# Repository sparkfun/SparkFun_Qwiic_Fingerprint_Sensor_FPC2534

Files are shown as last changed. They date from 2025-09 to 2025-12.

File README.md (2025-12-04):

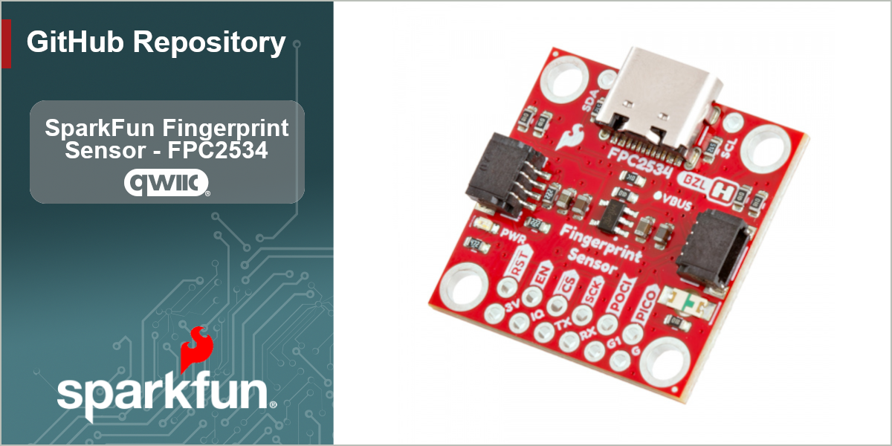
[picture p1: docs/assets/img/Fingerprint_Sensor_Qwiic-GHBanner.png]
SparkFun Fingerprint Sensor - FPC2534 (Qwiic) (https://www.sparkfun.com/sparkfun-fingerprint-sensor-fpc2534-qwiic.html)


---------------------

The SparkFun FPC2534 Qwiic Fingerprint Sensor is a powerful, dual-purpose breakout that combines professional-grade biometric security with touch navigation. Built around the advanced FPC2354 sensor from Fingerprint Cards AB (FPC), this board handles the complex processing of fingerprint enrollment, encryption, and internal storage, ensuring your data remains secure without bogging down your host microcontroller.

This sensor is a complete authentication scanner designed for our [Qwiic ecosystem](https://www.sparkfun.com/qwiic). Whether you are creating a secure access terminal, a hardware password manager, or a smart lock, the FPC2534 Fingerprint Sensor will provide you with reliable security in low-profile package.

Repository Contents
-------------------

* **/docs** - Documentation files for GitHub pages
* **/Documentation** - Data sheets, additional product information 
* **/Hardware** - Eagle design files (.brd, .sch)
* **/Production** - Production panel files (.brd)

Documentation
--------------
* **[Library](https://github.com/sparkfun/SparkFun_FPC2534_Arduino_Library)** - Arduino library for the SparkFun Fingerprint Sensor - FPC2534 (Qwiic).
* **[Hookup Guide](https://docs.sparkfun.com/SparkFun_Qwiic_Fingerprint_Sensor_FPC2534/)** - Basic hookup guide for the SparkFun Fingerprint Sensor - FPC2534 (Qwiic).

Product Versions
----------------
* [SEN-29854](https://www.sparkfun.com/sparkfun-fingerprint-sensor-fpc2534-qwiic.html) - Initial release of the SparkFun Fingerprint Sensor - FPC2534 (Qwiic)

License Information
-------------------

This product is _**open source**_! 

Please review the LICENSE.md file for license information. 

If you have any questions or concerns on licensing, please contact technical support on our [SparkFun forums](https://forum.sparkfun.com/viewforum.php?f=152).

Distributed as-is; no warranty is given.

- Your friends at SparkFun.

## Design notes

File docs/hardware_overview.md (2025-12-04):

Let's take a closer look at the FPC2534 sensor and other hardware on this Qwiic breakout.

<figure markdown>
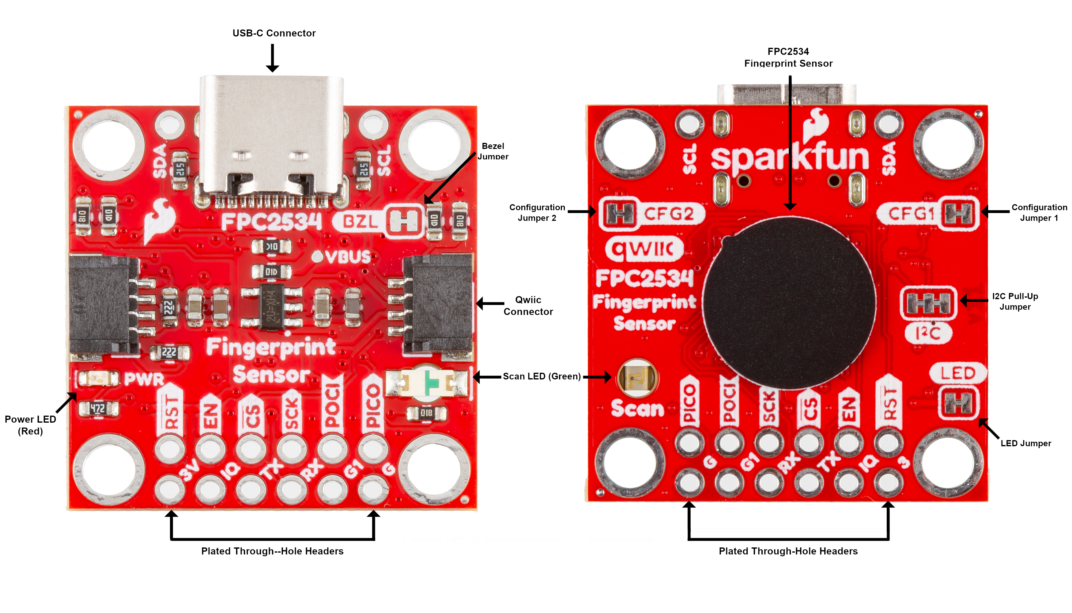
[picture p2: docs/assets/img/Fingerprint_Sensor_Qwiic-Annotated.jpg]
Annotated image of the Qwiic Fingerprint Sensor

</figure>

## FPC2534 Fingerprint Sensor

The FPC2534 fingerprint sensor is a compact fingerprint sensor capable of enrolling and storing up to 45 fingerprint templates and also has a four-way navigation feature.  The FPC2534 has a low-profile design that includes a hidden bezel tied to four ground pins. It communicates over UART, I<sup>2</sup>C, SPI and USB. It runs best powered with **3.3V** with a max current draw of ~**21mA** during active mode. For complete information on the FPC2534, refer to the [datasheet](./assets/component_documentation/SPC27317-5%20FPC2530.pdf).

The sensor automatically creates and stores fingerprint templates as they are added in the device's flash memory. The FPC2534 also supports encrypted communication with a host device though this feature must be enabled by sending an AES key from the host to the FPC2534. For more information on enabling this feature, refer to the [Supplemental Information](./assets/component_documentation/spc27387-2-fpc2534-allkey-pro-supplement.pdf) document. 

## Connectors and Pinout

### USB-C

The board has a USB-C connector to use the FPC2534 over its USB interface. The <b>5V</b> supply voltage from USB is regulated down to <b>3.3V</b> to safely power the FPC2534 over USB.

### Qwiic

The pair of Qwiic connectors on the board . Note, communicating with the FPC2534 over I<sup>2</sup>C requires connecting the Interrupt Request (IRQ) pin to the host microcontroller. 

### PTHs and Bezel Mounts

The board has a pair of 0.1"-spaced plated through-hole (PTH) headers that break out a majority of the FPC2534's pins.

We've also plated all four mounting holes and connected them to the board's ground bezel for optimal performance.

## LEDs

This board has a pair of LEDs labeled <b>PWR</b> and <b>Scan</b>. The red <b>PWR</b> LED indicates whenever the board has power. The green <b>Scan</b> LED is software controlled and tied to GPIO1 on the FPC2534. 

## Solder Jumpers

There are five solder jumpers on this board labeled: <b>CFG1</b>, <b>CFG2</b>, <b>I2C</b>, <b>LED</b> and <b>BZL</b>. The list below outlines their functionality, default states and any notes on their use.

* <b>I<sup>2</sup>C</b> - Pulls the FPC2534's I<sup>2</sup>C lines (SDA/SCL) to <b>3.3V</b> through a pair of <b>2.2k&ohm;</b> resistors. This jumper is CLOSED by default. Open it to disable pullups on these lines.
* <b>LED</b> - This jumper completes the Power LED circuit and is CLOSED by default. Open the jumper to disable the power LED.
* <b>BZL</b> - This jumper ties the FPC2534's bezel ground plane to the sensor's main ground and is CLOSED by default. Open this jumper to isolate the bezel ground from the main ground plane.
* <b>CFG1</b> & <b>CFG2</b> - These two jumpers control the interface selection for the FPC2534. The table below outlines the interface options and their corresponding jumper states:

<table>
    <tr>
        <th>Interface</th>
        <th>CFG1</th>
        <th>CFG2</th>
    </tr>
    <tr>
        <td>I<sup>2</sup>C (Default)</td>
        <td>CLOSED</td>
        <td>CLOSED</td>
    </tr>
    <tr>
        <td>USB</td>
        <td>OPEN</td>
        <td>CLOSED</td>
    </tr>
    <tr>
        <td>UART</td>
        <td>CLOSED</td>
        <td>OPEN</td>
    </tr>
    <tr>
        <td>SPI</td>
        <td>OPEN</td>
        <td>OPEN</td>
    </tr>
</table>

## Board Dimensions

The SparkFun Fingerprint Sensor - FC2534 (Qwiic) matches the 1"x1" (25.4mm x 25.4mm) and has four mounting holes that fit a 4-40 screw. Note, all four of the mounting holes are plated to allow users to ground the board to their mount through these holes.

<figure markdown>
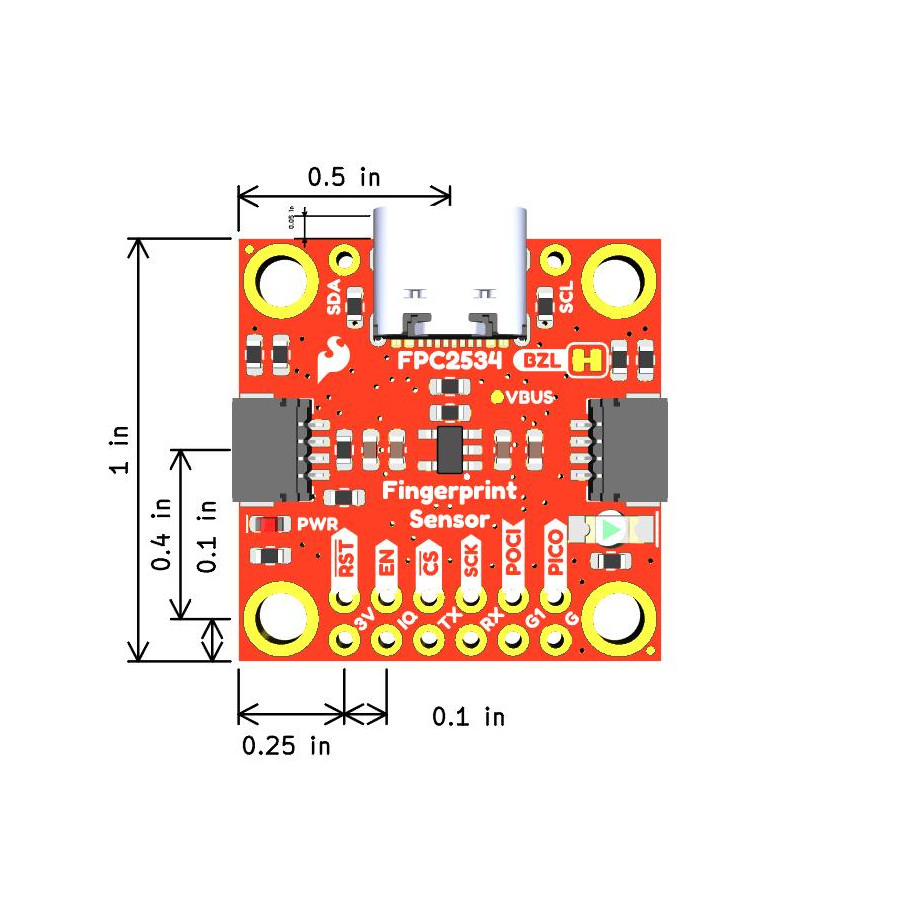
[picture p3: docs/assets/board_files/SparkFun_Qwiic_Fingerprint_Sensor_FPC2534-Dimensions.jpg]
Board dimensions

</figure>

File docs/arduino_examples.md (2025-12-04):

The SparkFun FPC2534 Arduino Library contains four examples that demonstrate how to use the fingerprint sensor over either I<sup>2</sup>C, UART or SPI. Reminder, communicating with the Fingerprint Sensor over USB is <i>not</i> supported by this library. Each pair of examples (I2C, UART, SPI) perform the same actions just over the different interface options so we'll just be covering the first two for I<sup>2</sup>C.

!!! arduino
    If you're following along and using the RedBoard IoT - RP2350, make sure you've installed the "arduino-pico" boards package before uploading the code. If you need help installing the boards package, you can find detailed instructions for it [here](https://docs.sparkfun.com/SparkFun_IoT_RedBoard-RP2350/arduino/#arduino-pico-boards).

## Example 01 - Navigation I<sup>2</sup>C

The first example shows how to use the FPC2534's navigation tools to register movement on the sensing area. This navigation recognizes swiping Up, Down, Left and Right and also a press and hold to turn the green SCAN LED on and off. Open the example by navigating to **File** > **Examples** > **SparkFun FPC2534 Arduino Library** > **Example01_NavigationI2C**. 

The example defaults to work with a RedBoard IoT - ESP32 so if you're using a different board like the RedBoard IoT - RP2350 we used in the Hardware Assembly section, you'll need to adjust the pin definitions to switch to the correct board. For example, to switch to using the RedBoard IoT - RP2350, comment out the defines for the ESP32 like this:

``` c++
// ESP32 IoT RedBoard
// #define IRQ_PIN 26
// #define RST_PIN 27
// #define I2C_BUS 0
```

And then uncomment the defines for the RedBoard IoT - RP2350:

``` c++
// rp2350 RedBoard IoT
#define IRQ_PIN 29
#define RST_PIN 28
#define I2C_BUS 0
```

After editing the example, select your Board and Port and click the "Upload" button. Once the code finishes compiling and uploading, open the [serial monitor](https://docs.arduino.cc/software/ide-v2/tutorials/ide-v2-serial-monitor) with the baud set to **115200** and you should see the following print out:

<figure markdown>
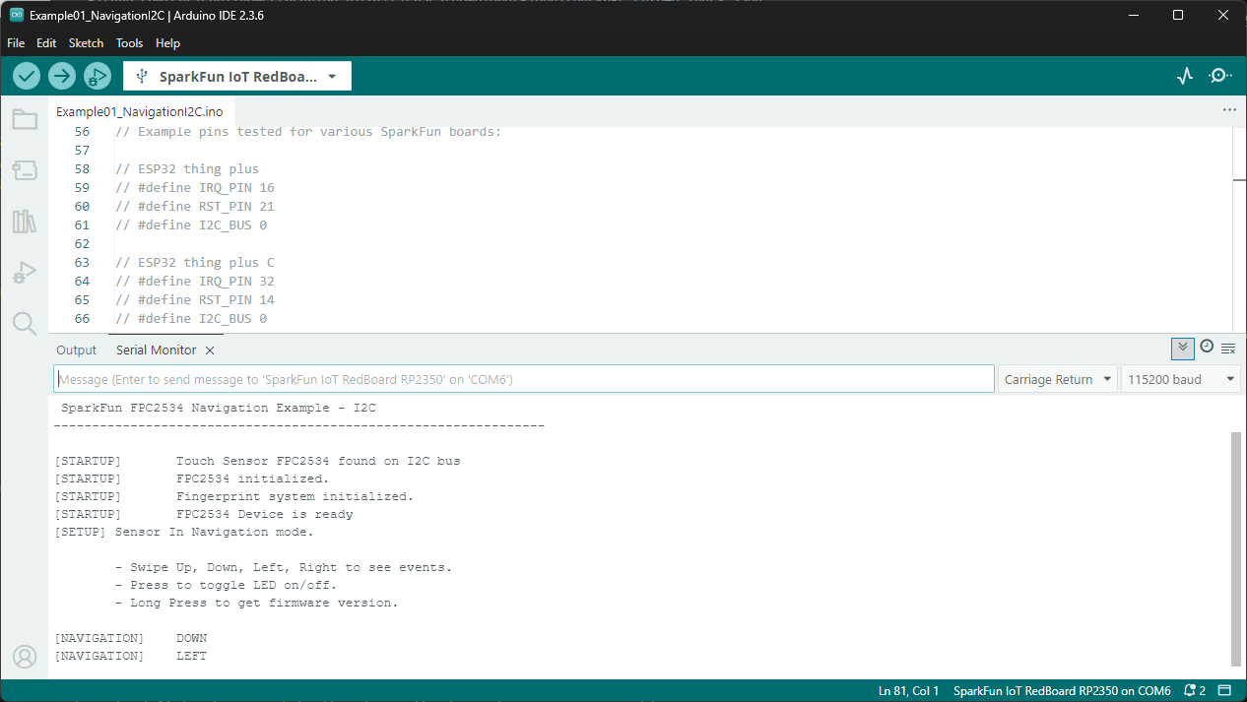
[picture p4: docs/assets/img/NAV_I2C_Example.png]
Screenshot of serial print out for Example 01 - NAVI2C

</figure>

Try swiping your finger over the sensing area in different directions and you should see a print out to the corresponding direction (Up, Down, Left or Right). You can also press your finger down on the sensor to turn the scan LED on and off or press and hold it to print out the sensor's firmware version.

## Example 02 - Enrollment I<sup>2</sup>C

The second example shows how to create, verify and erase fingerprint templates on the FPC2534. Open the example by navigating to **File** > **Examples** > **SparkFun FPC2534 Arduino Library** > **Example02_EnrollI2C**. 

Just like the previous example, this defaults to work with the RedBoard IoT - ESP32 so you'll need to adjust the pin definitions like we did above if you're using a different board like the RedBoard IoT - RPS2350. Copy the adjustments from Example 01 if needed. 

After editing the example, select your Board and Port and click the "Upload" button. Once the code finishes compiling and uploading, open the serial monitor with the baud set to **115200** and you should see the following menu print out:

<figure markdown>
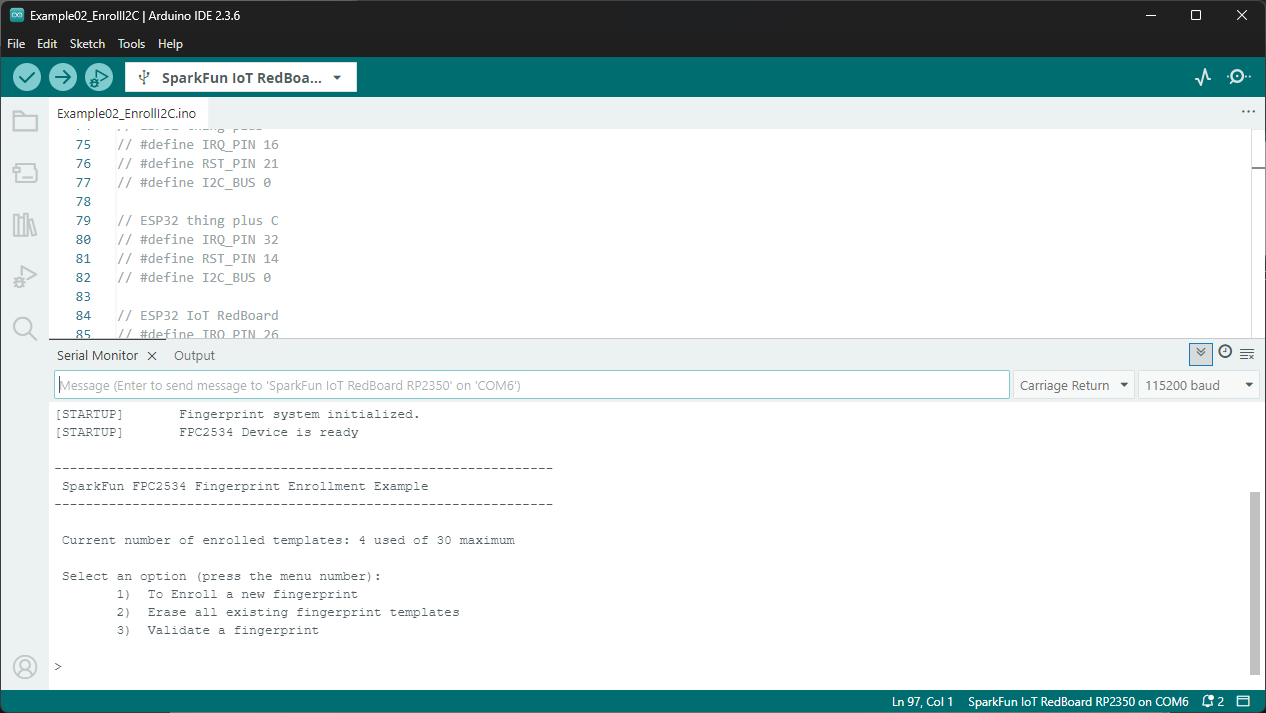
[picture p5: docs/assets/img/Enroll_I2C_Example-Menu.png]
Screenshot of serial menu for Example 2

</figure>

This menu gives you three options: enroll a new fingerprint template, erase all stored templates and verify a template. Enter "1" into the serial monitor to enroll a new fingerprint. Once you see the prompt for creating a new template, place and remove a finger on the sensor taking care to cover the entire sensing area. You'll need to repeat this step 12 times and it's recommended to place your finger at different orientations while still covering the entire sensor to create a reliable template. Once all samples are taken you'll see "done" and the code reverts back to the main menu:

<figure markdown>
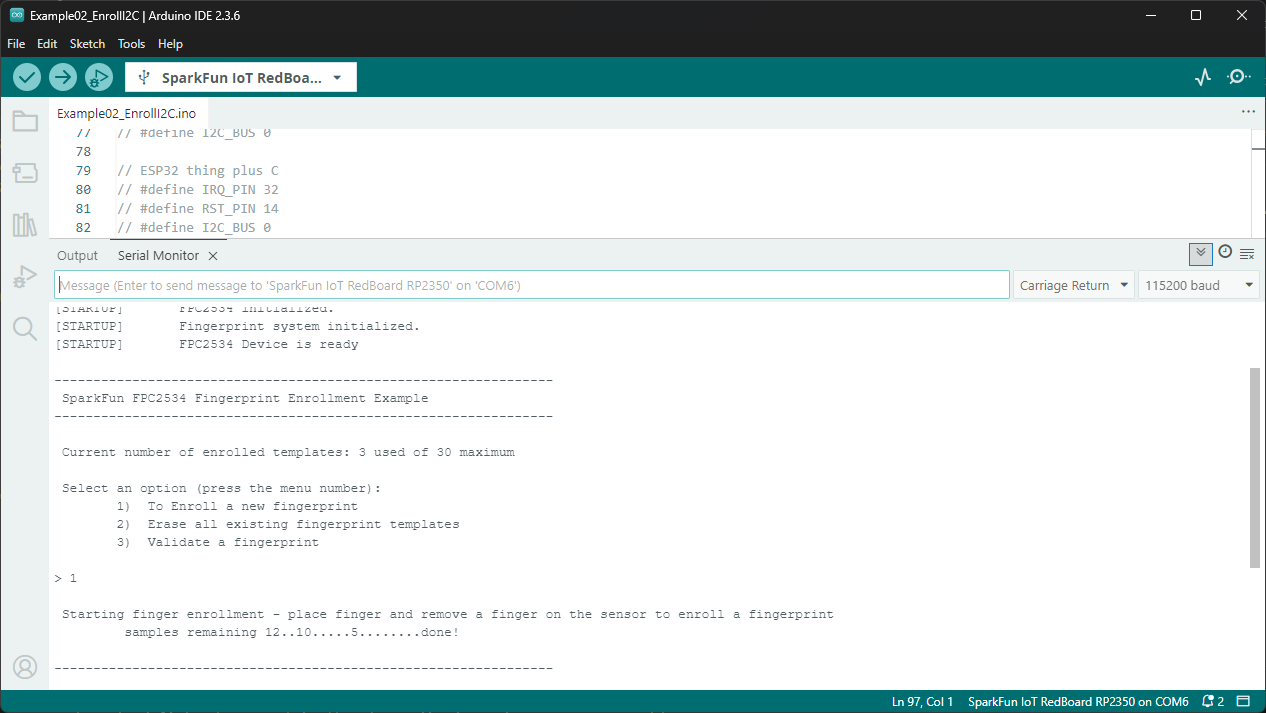
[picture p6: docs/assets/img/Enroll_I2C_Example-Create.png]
Screenshot of successful template creation in the serial monitor

</figure>

Now that we've created a new template, let's check to make sure we can validate it. Select option 3 "Validate a fingerprint" by entering "3" into the serial monitor input. The code will prompt to place a finger for validation and, if it matches a stored template it prints out "MATCH" along with the Template ID:

<figure markdown>
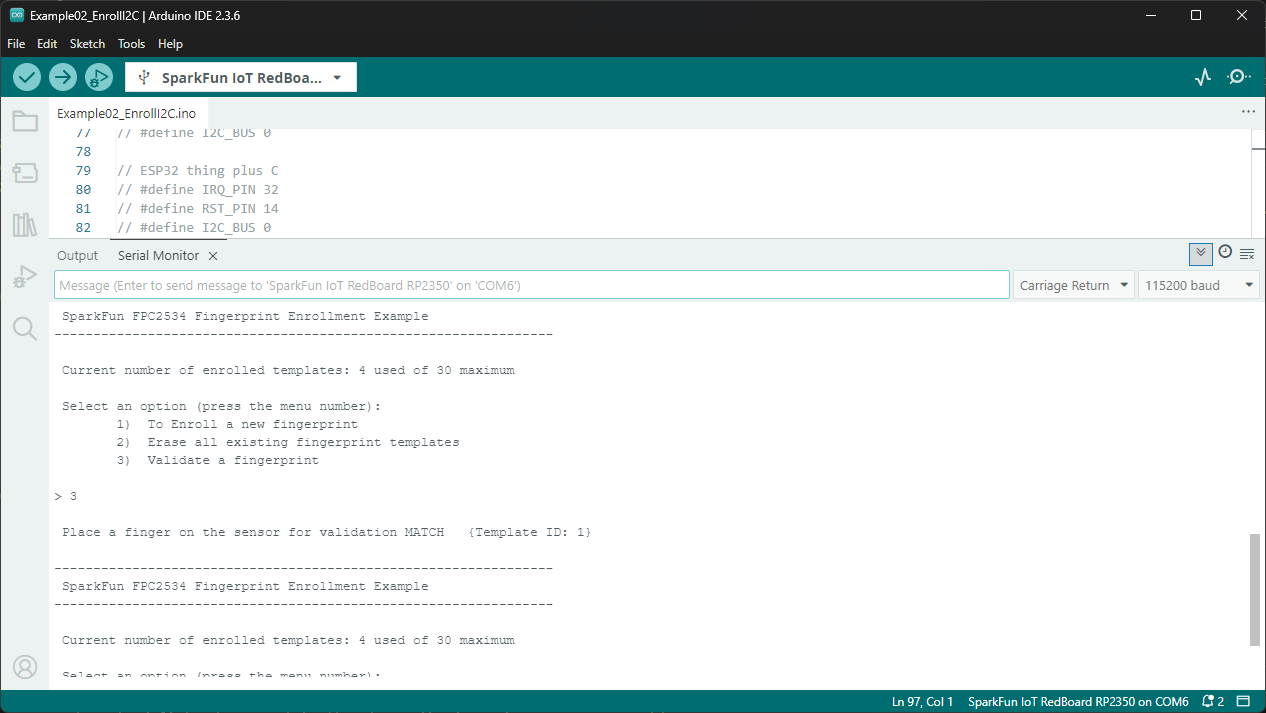
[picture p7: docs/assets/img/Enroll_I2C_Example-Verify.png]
Screenshot of successful fingerprint validation in the serial monitor

</figure>

You've now successfully created and validated a fingerprint template! You can use these stored templates to trigger whatever kind of output you'd like for your next fingerprint sensing project.

## Examples 3 through 6

The rest of the examples are copies of the Navigation and Enroll examples we covered above, just for UART and SPI so we won't be covering them in detail here.

!!! arduino 
    **Note:** The UART examples default to use `Serial1` on a connected development board so make sure to wire the Fingerprint Sensor's UART pins to your development board's Serial1 pins or adjust the code to use [software serial](https://docs.arduino.cc/learn/built-in-libraries/software-serial/) if needed.

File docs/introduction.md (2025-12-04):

<figure markdown>
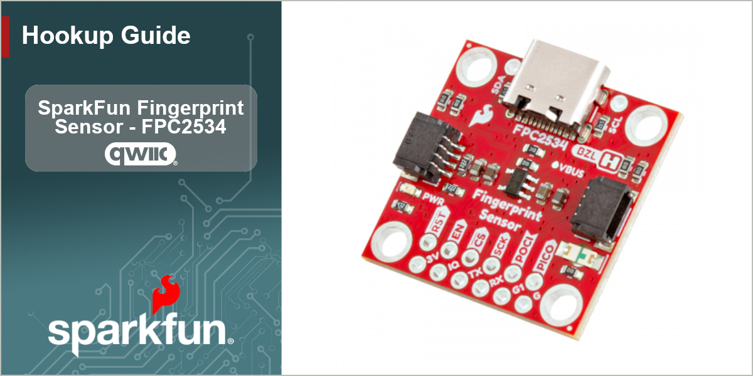
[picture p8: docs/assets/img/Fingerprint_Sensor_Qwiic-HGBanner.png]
Qwiic Fingerprint Scanner - FPC2534 Banner Image (https://www.sparkfun.com/sparkfun-fingerprint-sensor-fpc2534-qwiic.html)

</figure>

The SparkFun FPC2534 Qwiic Fingerprint Sensor is a powerful, dual-purpose breakout that combines professional-grade biometric security with touch navigation. Built around the advanced FPC2354 sensor from Fingerprint Cards AB (FPC), this board handles the complex processing of fingerprint enrollment, encryption, and internal storage, ensuring your data remains secure without bogging down your host microcontroller.

In order to follow along with this tutorial, you'll need the following materials along with the SparkFun Qwiic Fingerprint Sensor - FPC2534.

* [RedBoard IoT - RP2350](https://www.sparkfun.com/catalog/product/view/id/17811/s/sparkfun-iot-redboard-rp2350/) or [RedBoard IoT - ESP32](https://www.sparkfun.com/sparkfun-iot-redboard-esp32-development-board.html)
* [USB-C Cable](https://www.sparkfun.com/usb-a-to-usb-c-cable-1m-usb-2-0-flexible-silicone.html)
* [Qwiic Cable](https://www.sparkfun.com/flexible-qwiic-cable-100mm.html)

Communication with the FPC2534 over I<sup>2</sup>C requires connecting the Reset and Interrupt Request pins to GPIO pins on a microcontroller or development board. We'll be using male headers and jumper wires to make those connections:

* [Male Headers - Breakaway](https://www.sparkfun.com/header-1x20-male-0-1.html)
* [Jumper Wires](https://www.sparkfun.com/jumper-wires-premium-12-m-m-pack-of-10.html)

You'll also need a soldering iron and solder to use the breakout with a compatible development board. If you need either of those items, we have a selection of them available in our [Soldering category](https://www.sparkfun.com/tools/soldering.html).

## Topics Covered

This document contains three main sections: **Quickstart Guide**, **Hardware** and **Software**. 

The Quickstart Guide assumes a working knowledge of how to assemble and use Qwiic breakouts, perform through-hole soldering and using the Arduino IDE. It covers a quick assembly and then jumps right into getting the necessary software packages installed to start uploading code in just a few short minutes.

The Hardware pages cover a hardware overview that provides a detailed overview of the Qwiic Fingerprint Sensor - FPC2534 covering all the major components on the board in detail as well as a hardware assembly page which goes over the steps required to assemble and use the board with a compatible Arduino development board.

The Software pages give instructions on how to install the SparkFun FPC2534 Arduino Library and use the examples included in it.

## Resources and Documentation

You'll find the board design files (KiCad files & schematic), relevant documentation (datasheets, white papers, etc.) and other helpful links in the **Resources**. Lastly, the **Support** section includes a Troubleshooting page that includes any helpful tips specific to this board as well as information on how to receive technical support from SparkFun.

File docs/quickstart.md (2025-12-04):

In this quick start guide we'll show you how to assemble the SparkFun Fingerprint Sensor - FPC2534 (Qwiic) in a circuit with the SparkFun IoT RedBoard - RP2350 to enroll and read fingerprints over I<sup>2</sup>C. If you'd like to use this breakout in the other available communication interfaces (UART or SPI), read on to the [Hardware Overview](./hardware_assembly.md) and [Arduino Examples](./arduino_examples.md) pages of this guide.

<figure markdown>
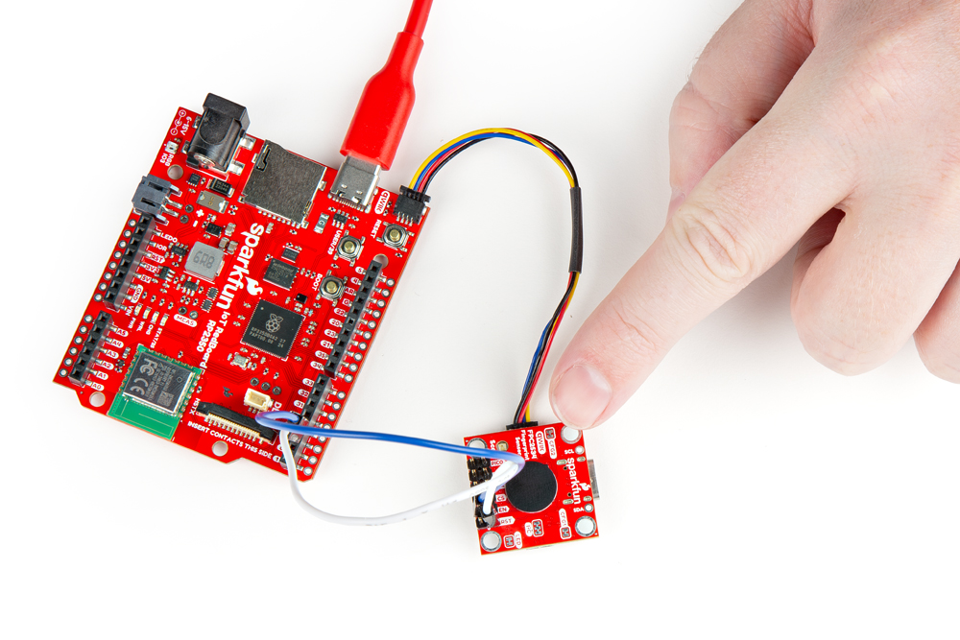
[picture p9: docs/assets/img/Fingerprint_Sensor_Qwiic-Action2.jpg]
Action image of fingerprint sensor demo

</figure>

This quick start guide assumes you have experience with the Arudino IDE; including installing and using Arduino boards packages and libraries, as well as basic knowledge of through-hole soldering and the Qwiic ecosystem. If you're not familiar with any of these topics or prefer to use this breakout over a different communication interface (UART or SPI), we recommend reading through the main Hookup Guide for the SparkFun Fingerprint Sensor - FPC2534 (Qwiic).

## Qwiic/I<sup>2</sup>C Assembly

This Qwiic breakout is different than most of them as it requires connecting the FPC2534's Reset (RST) and Interrupt Request (IQ) pins to the host to properly communicate over I<sup>2</sup>C. Because of this, we went ahead and soldered headers to the PTH pins broken out on the board to make these connections using jumper wires. Follow the steps below to connect the Qwiic Fingerprint Sensor to the RedBoard IoT - RP2350:

* Solder headers (or wires if you prefer) to the Qwiic Fingerprint Sensor's PTH pins.
* Connect the Qwiic Fingerprint Sensor to the RedBoard IoT with a Qwiic cable.
* Connect the FPC2534's Reset pin to <code>28</code> and the Interrupt Request pin to <code>29</code> on the RedBoard IoT.
* Connect the RedBoard IoT to your computer using a USB-C cable.

After wiring everything up, your circuit should look similar to this photo:

<figure markdown>
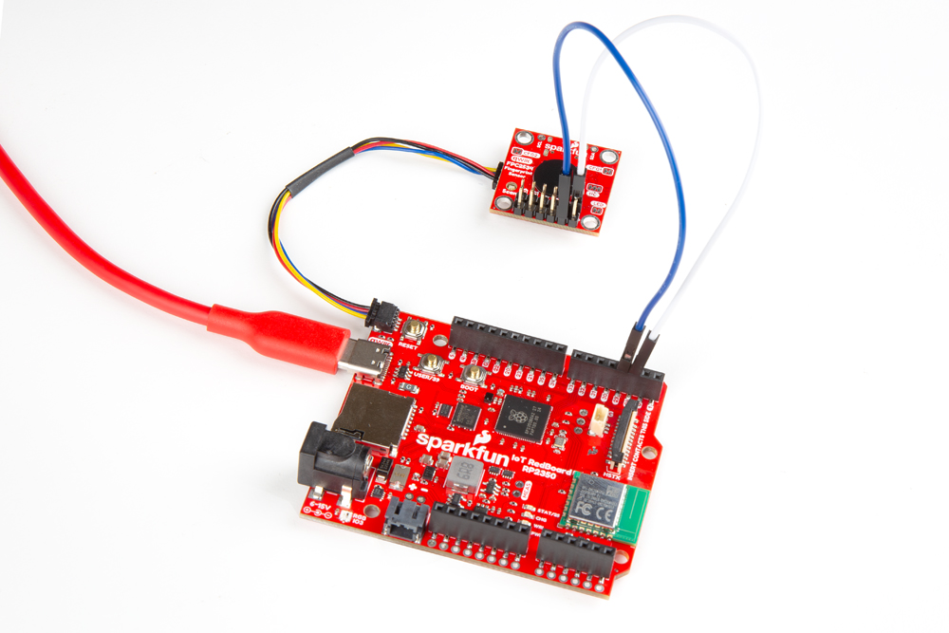
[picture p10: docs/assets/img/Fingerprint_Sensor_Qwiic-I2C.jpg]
Completed Qwiic/I2C assembly

</figure>

## Arduino Example - Enroll Fingerprint I2C

Let's move on to installing the SparkFun FPC2534 Arduino library (and boards packages if needed) to enroll and validate fingerprint templates. Follow these steps to upload and run the "Enroll I2C" example.

* Install the SparkFun FPC2534 Arduino library using the [library manager](https://docs.arduino.cc/software/ide-v2/tutorials/ide-v2-installing-a-library/) by searching for "SparkFun FPC2534".
* If you don't already have the RedBoard IoT - RP2350 board definitions installed, you'll need to install the "arduino-pico" boards package. Copy this JSON URL: <code>https://github.com/earlephilhower/arduino-pico/releases/download/global/package_rp2040_index.json
</code> to the "Additional Boards Manager URLs" in the "Preferences" menu and then search for "arduino-pico" in the [boards manager](https://docs.arduino.cc/software/ide-v2/tutorials/ide-v2-board-manager) tool and install the latest version.
* Open "Example02_EnrollI2C". The example defaults to work with the RedBoard IoT - ESP32 so we need to comment these defines out:
``` c++
// ESP32 IoT RedBoard
#define IRQ_PIN 26
#define RST_PIN 27
#define I2C_BUS 0
```
* Next, uncomment these defines to switch to the RedBoard IoT - RP2350:
``` c++
// #define IRQ_PIN 29
// #define RST_PIN 28
// #define I2C_BUS 0
```
* Now that the code is switched to work with the RP2350, select your board and port and click "Upload".

Once the code finishes compiling, open the [serial monitor](https://docs.arduino.cc/software/ide-v2/tutorials/ide-v2-serial-monitor) with the baud set to **115200** and you should see the following menu:

<figure markdown>
Screenshot of serial menu for Example 2
</figure>

This menu gives you three options: enroll a new fingerprint template, erase all stored templates and verify a template. Enter "1" into the serial monitor to enroll a new fingerprint. Once you see the prompt for creating a new template, place and remove a finger on the sensor taking care to cover the entire sensing area. You'll need to repeat this step 12 times and it's recommended to place your finger at different orientations while still covering the entire sensor to create a reliable template. Once all samples are taken you'll see "done" and the code reverts back to the main menu:

<figure markdown>
Screenshot of successful template creation in the serial monitor
</figure>

Now that we've created a new template, let's check to make sure we can validate it. Select option 3 "Validate a fingerprint" by entering "3" into the serial monitor input. The code will prompt to place a finger for validation and, if it matches a stored template it prints out "MATCH" along with the Template ID:

<figure markdown>
Screenshot of successful fingerprint validation in the serial monitor
</figure>

You've now successfully created and validated a fingerprint template! You can use these stored templates to trigger whatever kind of output you'd like for your next fingerprint sensing project.

### Code to Note

This example uses several [static variables](https://docs.arduino.cc/language-reference/en/variables/variable-scope-qualifiers/static/) to perform the various functions in this example to preserve the data from them between function calls. Let's take a look at a couple of them as they can be useful to get valuable data from the FPC2534 to perform other actions in your own code. For example, you'll probably want to use a successful template verification to trigger some result aside from just a serial print.

**`on_identify()`**

The `on_identify()` static variable is called when the sensor sends an identify result. This returns whether or not there was a match along with the template ID on a match and prints out the result and ID:

``` c++
static void on_identify(bool is_match, uint16_t id)
{

    Serial.print(is_match ? "" : " NO ");
    Serial.print(" MATCH ");

    if (is_match)
    {
        Serial.print("  {Template ID: ");
        Serial.print(id);
        Serial.print("}");
    }
    Serial.println();
}
```

**`on_enroll()`**

The `on_enroll()` static variable is called when the sensor sends an enroll result. It checks to see how many samples remain to be entered and returns done when that value hits 0:

``` c++
static void on_enroll(uint8_t feedback, uint8_t samples_remaining)
{
    // Done?
    if (samples_remaining == 0)
    {
        Serial.println("..done!");
        delay(500); // user feedback...
        numberOfTemplates++;
    }
    else
    {
        Serial.print(samples_remaining);
        Serial.print(".");
    }
}
```

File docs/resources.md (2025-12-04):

For more information about the SparkFun Qwiic Fingerprint Sensor - FPC2534, check out the following resources:

* [Schematic](./assets/board_files/SparkFun_Qwiic_Fingerprint_Sensor_FPC2534.pdf)
* [KiCad Files](./assets/board_files/SparkFun_Qwiic_Fingerprint_Sensor_FPC2534.zip)
* [Board Dimensions](./assets/board_files/SparkFun_Qwiic_Fingerprint_Sensor_FPC2534-Dimensions.jpg)
* [Datasheet](./assets/component_documentation/) (FPC2534)
* [Product Specification](./assets/component_documentation/) (FPC2534)
* [FPC2534 Arduino Library](https://github.com/sparkfun/SparkFun_FPC2534_Arduino_Library)
* [GitHub Repository](https://github.com/sparkfun/SparkFun_Qwiic_Fingerprint_Sensor_FPC2534)
* [Qwiic Info Page](https://www.sparkfun.com/qwiic)

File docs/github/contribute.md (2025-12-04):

# Contribute: Make an Augmentation!
Spot an improvement opportunity? Feel free to contribute to our open-source design and documentation. 

## :material-file-document-multiple:&nbsp;Improve our Documentation
All of this documentation can be modified by you! Please help us make it better.

* These pages are contained in the [`docs` folder](https://github.com/sparkfun/SparkFun_Qwiic_Fingerprint_Sensor_FPC2534/tree/main/docs) of the [SparkFun Qwiic Fingerprint Sensor - FPC2534 Hookup Guide repository](https://github.com/sparkfun/SparkFun_Qwiic_Fingerprint_Sensor_FPC2534).

<!-- ### :material-source-pull:&nbsp;Submit a Correction -->
### Submit a Correction

1. With a GitHub account, [fork this repository](https://github.com/sparkfun/SparkFun_Qwiic_Fingerprint_Sensor_FPC2534/fork).
2. Add your corrections or improvements to the markdown file.
3. File a pull request with your changes, and enjoy making the ~~words~~ ~~worlds~~ world a better place.
	* Once received, the documentation specialist will automatically be notified.
	* We will review your suggested improvements to make sure they are correct and fit within our documentation standards.

## :material-cog:&nbsp;Improve our Hardware Design
All of our designs are open-source! Please help us make it better.

* Our board design files are contained in the [`Hardware` folder](https://github.com/sparkfun/SparkFun_Qwiic_Fingerprint_Sensor_FPC2534/tree/main/Hardware) of the [SparkFun Qwiic Fingerprint Sensor - FPC2534 Hookup Guide repository](https://github.com/sparkfun/SparkFun_Qwiic_Fingerprint_Sensor_FPC2534).

<!-- ### :material-source-pull:&nbsp;Submit a Design Enhancement -->
### Submit a Design Enhancement

1. With a GitHub account, [fork this repository](https://github.com/sparkfun/SparkFun_Qwiic_Fingerprint_Sensor_FPC2534/fork).
2. Add your design augmentation(s)
3. File a pull request with your changes, and enjoy making the ~~words~~ ~~worlds~~ world a better place.
	1. Once received, the engineer in charge of the original design will automatically be notified.
	2. We will review your suggested improvement(s) to verify that they are within our board design standards and meet our product design requirements.
	3. If approved, we will flag these changes for our next board revision. Congrats! 🍻

		!!! info
			Even if your suggestion is accepted, these changes may not be immediately available for purchase. We may have to cycle through our current product inventory first.

## Contributors&nbsp;:clap:
Let's provide some recognition to the contributors for this project!

GitHub Contributors Image
<br>


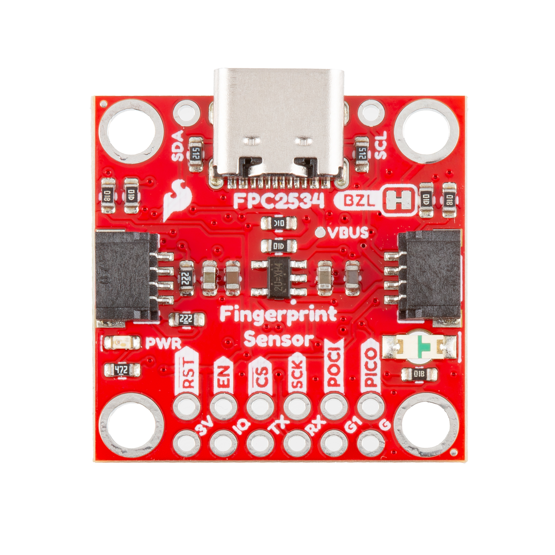
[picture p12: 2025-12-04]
docs/assets/img/29854-Fingerprint-Scanner-Front-high-res.jpg

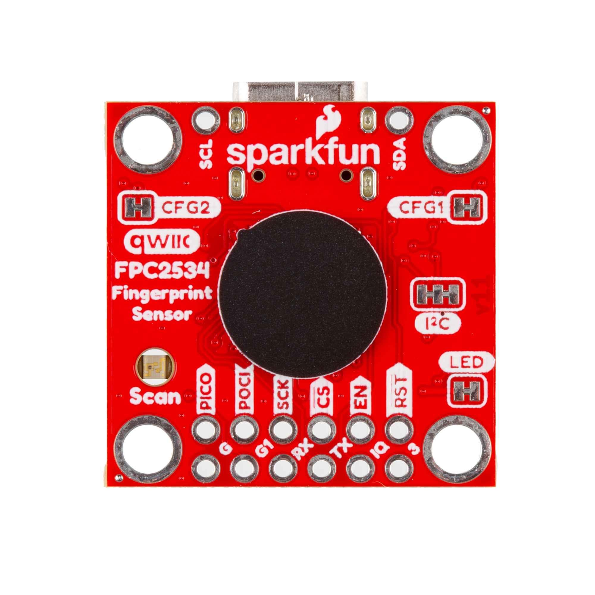
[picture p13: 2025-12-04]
docs/assets/img/29854-Fingerprint-Scanner-Back-high-res.jpg

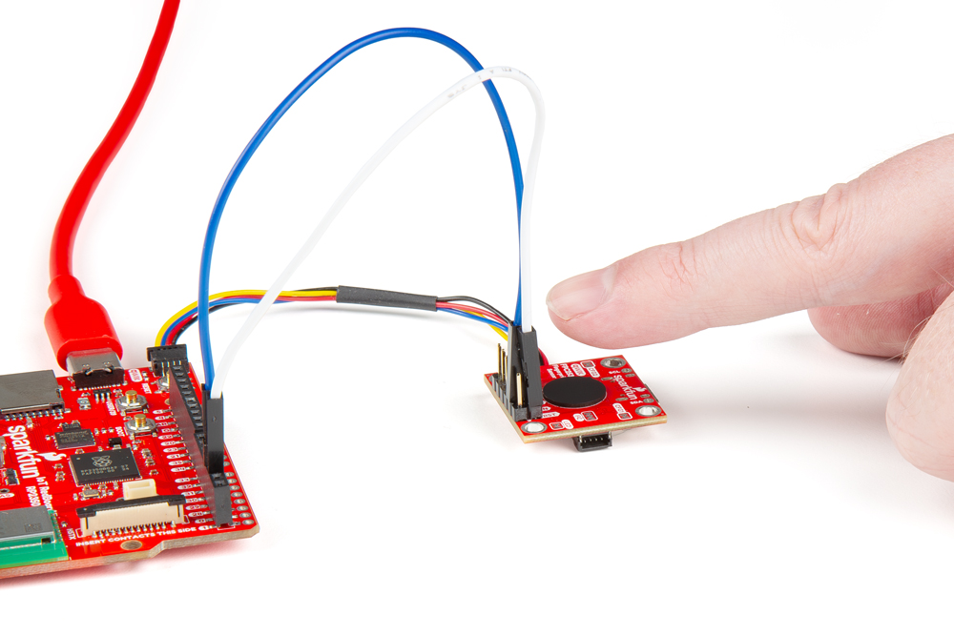
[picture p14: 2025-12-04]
docs/assets/img/Fingerprint_Sensor_Qwiic-Action.jpg

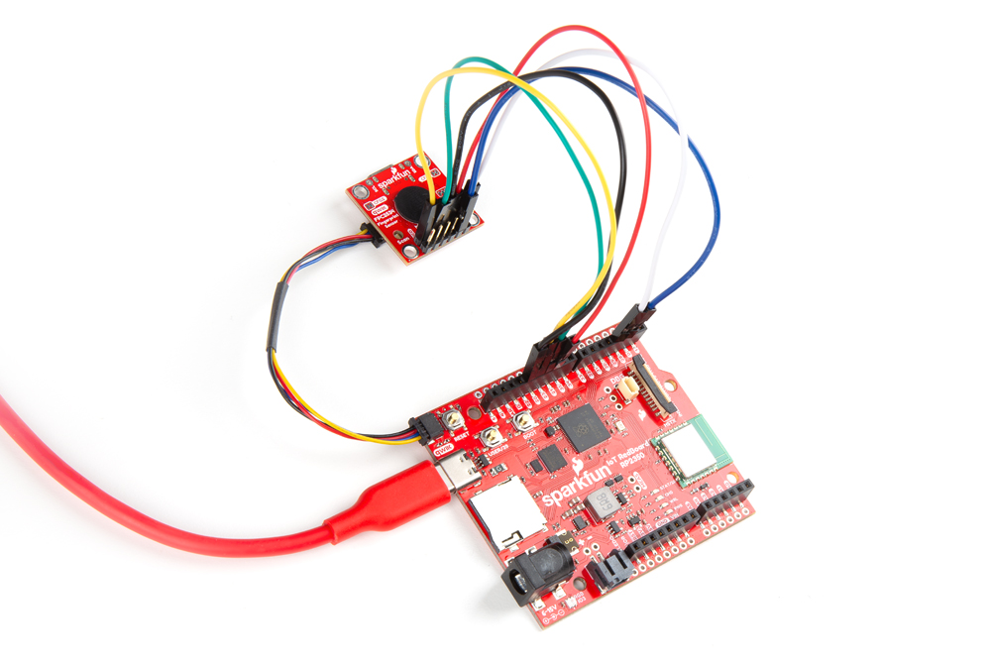
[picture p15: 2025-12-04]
docs/assets/img/Fingerprint_Sensor_Qwiic-SPI.jpg

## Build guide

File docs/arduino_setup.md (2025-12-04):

!!! arduino
    This example assumes you are using the latest version of the Arduino IDE on your desktop. If this is your first time using Arduino IDE, library, or board add-on, please review the following tutorials.

    - [Installing the Arduino IDE](https://learn.sparkfun.com/tutorials/installing-arduino-ide)
    - [Installing an Arduino Library](https://learn.sparkfun.com/tutorials/installing-an-arduino-library)
    - [Installing Board Definitions in the Arduino IDE](https://learn.sparkfun.com/tutorials/installing-board-definitions-in-the-arduino-ide)

## SparkFun FPC2534 Arduino Library

The SparkFun FPC2534 Arduino Library examples demonstrating how to use the FPC2534's main features including fingerprint enrollment, fingerprint template management and navigation over either I<sup>2</sup>C or UART. You can install the library with the Arduino [Library manager](https://docs.arduino.cc/software/ide-v2/tutorials/ide-v2-installing-a-library/) tool by searching for "SparkFun FPC2534". If you'd prefer a manual install, you can download a ZIP of the library [here](https://github.com/sparkfun/SparkFun_FPC2534_Arduino_Library/archive/refs/heads/main.zip).

!!! note "Supported Boards"
    The I<sup>2</sup>C (Qwiic) interface for the SparkFun Fingerprint Sensor - FPC2534 Pro board is currently only supported on ESP32 and Raspberry RP2 (RP2040, RP2350) boards. The I2C Implemention of the FPC2534 device performs a dynamic payload transmission that is not supported by the Arduino Wire library. Because of this, a custom implementation is provided by this library for the ESP32 and RP2 platforms.

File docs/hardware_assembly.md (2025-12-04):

!!! note "Soldering and Solder Jumpers"

This Qwiic breakout is a bit unique as it requires some extra assembly beyond just connecting it to your development board using a Qwiic cable. Using it over I<sup>2</sup>C requires connecting the FPC2534's Reset and Interrupt Request pins to compatible GPIO pins on your microcontroller. Because of this, we opted to solder a pair of male headers to the PTHs on this breakout for easy prototyping and testing using jumper wires.

Before moving on to the assembly options below, solder either headers or wires to your Qwiic Fingerprint Sensor and then connect using your preferred interface.
## Qwiic Assembly

This Qwiic breakout requires some extra assembly compared to most of our Qwiic boards need as the FPC2534 needs to have its Reset (RST) Interrupt Request (IRQ) pins connected to GPIO pins on a microcontroller to work properly over I<sup>2</sup>C. 

After soldering, connect the Qwiic Fingerprint Sensor - FPC2534 to the IoT RedBoard - RP2350 using a Qwiic cable then connect the Reset pin to <code>28</code> and the Interrupt Request pin to <code>29</code>. With everything wired up, your circuit should look similar to the photo below:

<figure markdown>
Completed Qwiic Assembly with the RedBoard IoT - RP2350
</figure>

## UART Assembly

Enable the UART interface by opening the CFG2 jumper. Connect the Qwiic Fingerprint Sensor to the RedBoard IoT - RP2350 following the table below:

<table>
    <tr>
        <th>Fingerprint Sensor</th>
        <th>RedBoard IoT - RP2350</th>
    </tr>
    <tr>
        <td>TX</td>
        <td>1</td>
    </tr>
    <tr>
        <td>RX</td>
        <td>0</td>
    </tr>
    <tr>
        <td>RST</td>
        <td>28</td>
    </tr>
</table>

After wiring everything up, your circuit should look similar to this photo:

<figure markdown>
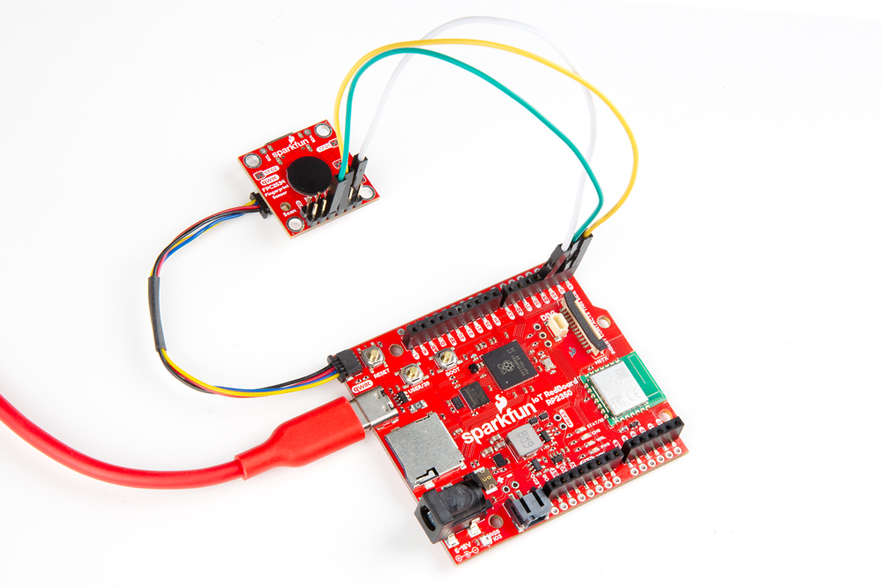
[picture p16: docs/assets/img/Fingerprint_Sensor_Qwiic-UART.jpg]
Completed UART assembly with the RedBoard IoT - RP2350

</figure>

## SPI Assembly

Finally, if you'd prefer to use the SPI interface, enable SPI by opening both config jumpers (CFG1 and CFG2). Connect the Fingerprint Sensor to the RedBoard IoT - RP2350 by following the table below: 

<table>
    <tr>
        <th>Fingerprint Sensor</th>
        <th>RedBoard IoT - RP2350</th>
    </tr>
    <tr>
        <td>PICO</td>
        <td>POCI</td>
    </tr>
    <tr>
        <td>POCI</td>
        <td>PICO</td>
    </tr>
    <tr>
        <td>SCK</td>
        <td>SCK</td>
    </tr>
    <tr>
        <td>CS</td>
        <td>5/CS</td>
    </tr>
</table>

## USB Assembly (Not supported)

If you'd like to use the Fingerprint Sensor as a USB device, enable the USB interface by opening the CFG1 jumper and then connect it to a USB host device over USB-C.

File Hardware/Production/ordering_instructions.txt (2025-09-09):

Ordering Instructions:
Panel dimensions: 142.70 x 160.99 mm.
Material: TG135
Solder Mask: Red
Silkscreen Color: White
Layers: 4
Finish: HASL Lead-Free
Thickness: 1.6mm
Outer Copper Weight: 1oz
Minimum track width: 0.15mm (6.00mil)
Minimum via drill: 0.30mm (11.81mil)

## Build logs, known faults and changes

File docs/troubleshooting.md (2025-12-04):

## Arduino Library Limitations

Reminder, the SparkFun FPC2534 Arduino Library currently only supports ESP32 and Raspberry RP2 (RP2040, RP2350) boards when using I<sup>2</sup>C. The I<sup>2</sup>C Implemention of the FPC2534 device performs a dynamic payload transmission that is not supported by the Arduino Wire library. Because of this, a custom implementation is provided by this library for the ESP32 and RP2 platforms. If you'd like to create your own custom implementation for a different processor, you can take a look at I<sup>2</sup>C helpers we made for the ESP32 and RP2 processors [here](https://github.com/sparkfun/SparkFun_FPC2534_Arduino_Library/tree/main/src/sfTk).

## General Troubleshooting

!!! note
    <span class="glyphicon glyphicon-question-sign" aria-hidden="true"></span>
        <strong> Not working as expected and need help? </strong> <br /><br />

    If you need technical assistance and more information on a product that is not working as you expected, we recommend heading on over to the <a href="https://community.sparkfun.com/">SparkFun Forums</a> to get help from our Technical Support team and community. If this is your first visit, you'll need to create a forum account to search product forums and post questions.<br /><br />

    <div style="text-align: center"><a href="https://community.sparkfun.com/" class="md-button md-button--primary">Log Into SparkFun Forums</a></div>

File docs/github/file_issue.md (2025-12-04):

# Did we make a mistake?

Spot something wrong? Please let us know. 

<!-- Technical Assistance Box -->
!!! warning "Need Help?"
    If you need technical assistance or more information on a product that is not working as you expected, we recommend heading on over to the [SparkFun Technical Assistance](https://www.sparkfun.com/technical_assistance) forums for some initial troubleshooting. This **Submit Issues** page is not where users should seek assistance.
    
    !!! info "Account Registration Required"
        For your first visit to our forum, you'll need to create a [Forum Account](https://forum.sparkfun.com/ucp.php?mode=register) to post questions.

## Discrepancies in the Documentation

All of our documentation can be modified by you! Please help us make it better.

* The documentation files for these pages are contained in the [`docs` folder](https://github.com/sparkfun/SparkFun_Qwiic_Fingerprint_Sensor_FPC2534/tree/main/docs) of the [SparkFun Qwiic Fingerprint Sensor - FPC2534 Hookup Guide repository](https://github.com/sparkfun/SparkFun_Qwiic_Fingerprint_Sensor_FPC2534).

### 🔍 Spot something wrong?

If a section of the documentation is incorrect, please [open an issue](https://github.com/sparkfun/SparkFun_Qwiic_Fingerprint_Sensor_FPC2534/issues) and let us know.

### Do you have a suggested correction?

1. With a GitHub account, [fork this repository](https://github.com/sparkfun/SparkFun_Qwiic_Fingerprint_Sensor_FPC2534/fork).
2. Add your correction(s) or improvement(s) to the markdown file(s)
3. File a pull request with your changes, and enjoy making the ~~words~~ ~~worlds~~ world a better place.
	* Once received, the documentation specialist will automatically be notified.
	* We will review your suggested improvement(s) to make sure they are correct and fit within our documentation standards.

## Problems in the Hardware Design

All of our designs are open-source! Please help us make it better.

* Our board design files are contained in the [`Hardware` folder](https://github.com/sparkfun/SparkFun_Qwiic_Fingerprint_Sensor_FPC2534/tree/main/Hardware) of the [SparkFun Qwiic Fingerprint Sensor - FPC2534 Hookup Guide repository](https://github.com/sparkfun/SparkFun_Qwiic_Fingerprint_Sensor_FPC2534).

### Does something not make sense? 🤔

If part of the design is confusing, please [open an issue](https://github.com/sparkfun/SparkFun_Qwiic_Fingerprint_Sensor_FPC2534/issues) and let us know.

### Did we forget to include an important function of the board? 🤦

If part of the board's functionality is missing, please [open an issue](https://github.com/sparkfun/SparkFun_Qwiic_Fingerprint_Sensor_FPC2534/issues) and file a feature request.

!!! tip "Design Considerations"
	Please keep in mind that we may intentionally exclude certain functions of the board to meet our product design requirements.
	
	* *For example, our Qwiic Micro boards are intended to fit on a small board layout and only use I<sup>2</sup>C communication; therefore, we may not have the SPI and interrupt pins available for users.*

### Do you wish to contribute directly to improving the board design?

1. With a GitHub account, [fork this repository](https://github.com/sparkfun/SparkFun_Qwiic_Fingerprint_Sensor_FPC2534/fork).
2. Add your design augmentation(s)
3. File a pull request with your changes, and enjoy making the ~~words~~ ~~worlds~~ world a better place.
	1. Once received, the engineer in charge of the original design will automatically be notified.
	2. We will review your suggested improvement(s) to verify that they are within our board design standards and meet our product design requirements.
	3. If approved, we will flag these changes for our next board revision. Congrats! 🍻

		!!! info
			Even if your suggestion is accepted, these changes may not be immediately available for purchase. We may have to cycle through our current product inventory first.

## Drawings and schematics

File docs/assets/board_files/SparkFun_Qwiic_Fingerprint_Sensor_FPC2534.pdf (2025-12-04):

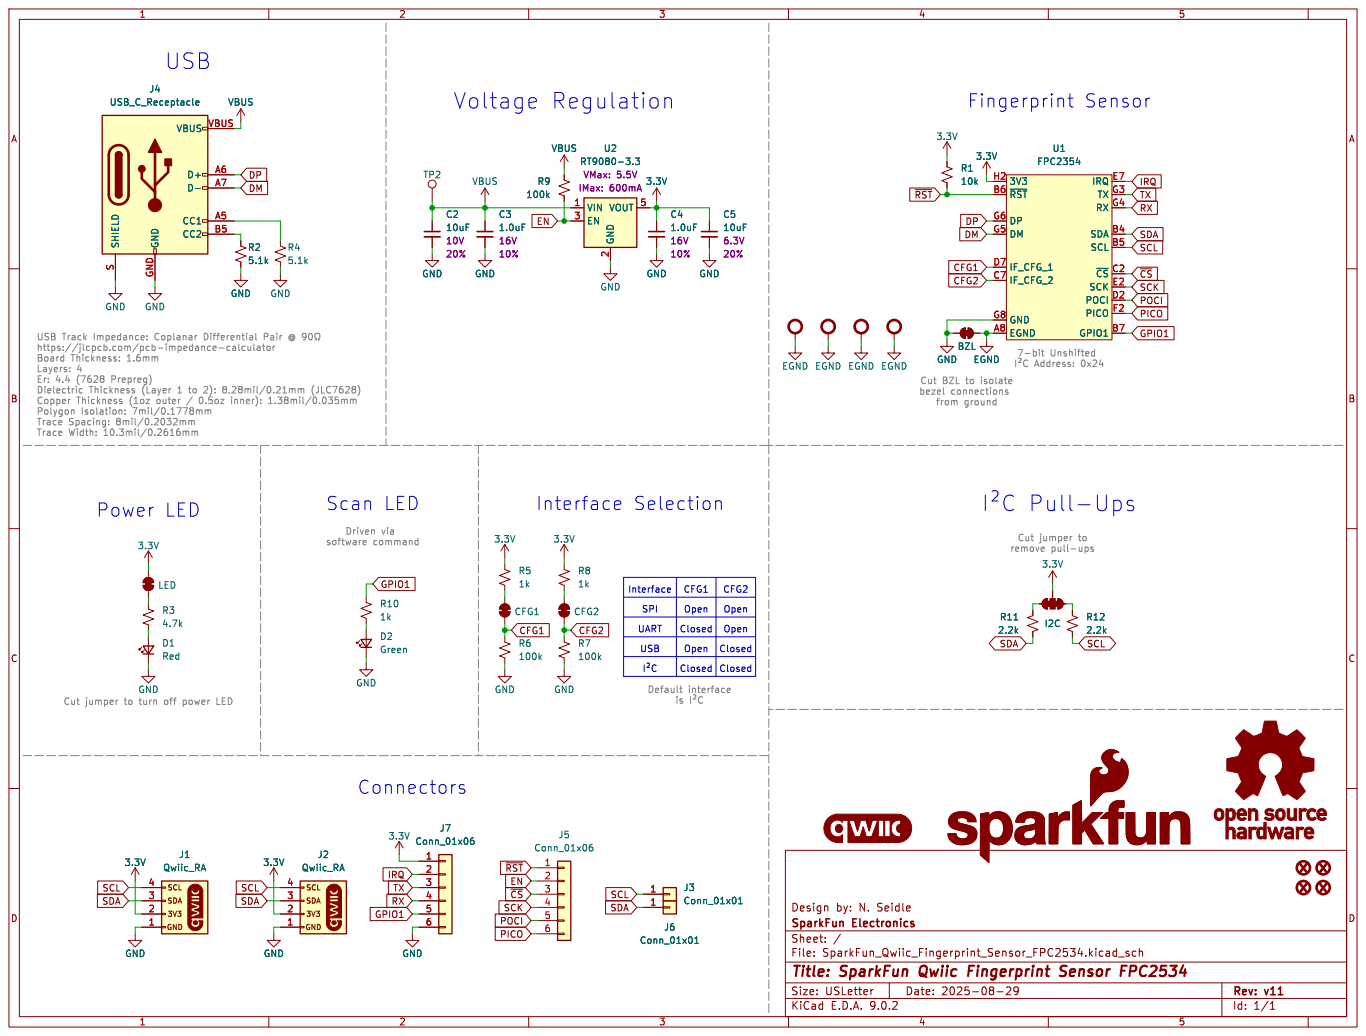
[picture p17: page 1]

IRQ E7 TX G3 RX G4 SDA B4 SCL B5 ~{CS} C2 SCK E2 POCI D2 PICO F2 GPIO1 B7 EGND

https://jlcpcb.com/pcb-impedance-calculator Board Thickness: 1.6mm

EGND EGND EGND GND

Copper Thickness (1oz outer / 0.5oz inner): 1.38mil/0.035mm
Trace Spacing: 8mil/0.2032mm

Open Closed Closed Default interface
UART

Cut jumper to turn off power LED

Id: 1/1 Title: SparkFun Qwiic Fingerprint Sensor FPC2534

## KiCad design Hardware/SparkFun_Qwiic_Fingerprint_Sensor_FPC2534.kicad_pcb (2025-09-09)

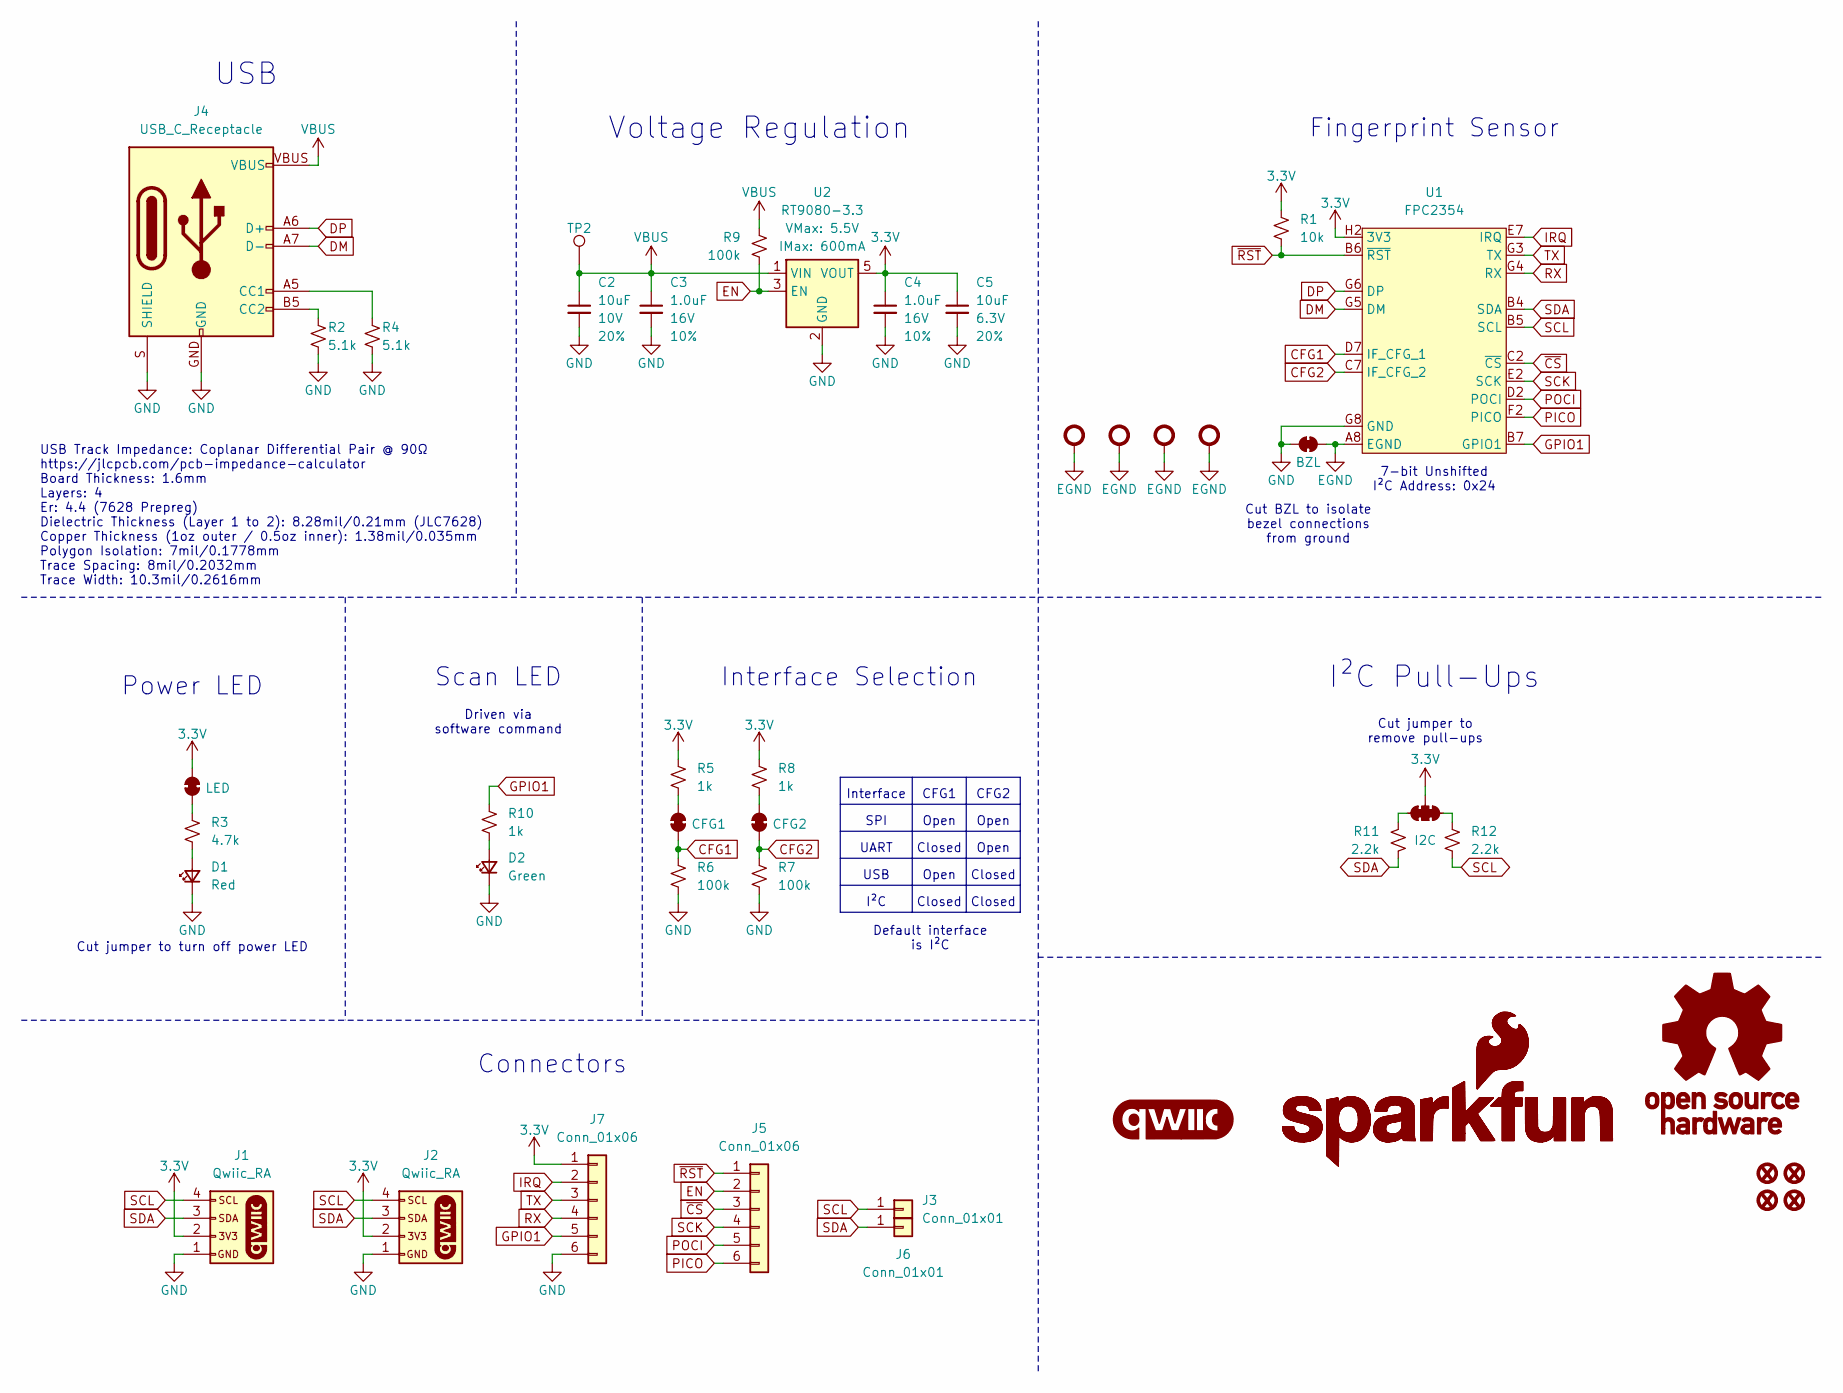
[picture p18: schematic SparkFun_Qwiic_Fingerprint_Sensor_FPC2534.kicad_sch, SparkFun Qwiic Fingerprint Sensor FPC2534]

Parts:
C2: 10uF; C_0603_1608Metric; Voltage 10V; Tolerance 20%
C3, C4: 1.0uF; C_0603_1608Metric; Voltage 16V; Tolerance 10%
C5: 10uF; C_0603_1608Metric; Voltage 6.3V; Tolerance 20%
D1: Red; LED_0603_1608Metric_Red
D2: Green; LED_1206_Bottom_Green
FID1, FID2, FID3, FID4: Fiducial_0.5mm; Fiducial_0.5mm_Mask1mm
G1: qwiic_Logo
G2: SparkFun_Logo; SparkFun_Logo_8mm
G3: SparkFun_Logo
G4: OSHW_Logo; Creative_Commons_License
J1, J2: Qwiic_RA; JST_SMD_1.0mm-4_Black
J3, J6: Conn_01x01; 1x01
J4: USB_C_Receptacle; USB-C_16
J5, J7: Conn_01x06; 1x06
JP1: LED; Jumper_2_NC_Trace
JP2: CFG1; Jumper_2_NC_Trace
JP3: CFG2; Jumper_2_NC_Trace
JP4: I2C; Jumper_3_NC-2_Trace
JP5: BZL; Jumper_2_NC_Trace
R1: 10k; R_0603_1608Metric
R2, R4: 5.1k; R_0603_1608Metric
R3: 4.7k; R_0603_1608Metric
R5, R8, R10: 1k; R_0603_1608Metric
R6, R7, R9: 100k; R_0603_1608Metric
R11, R12: 2.2k; R_0603_1608Metric
ST5, ST6, ST7, ST8: Standoff; Standoff_Connected
TP2: TestPoint_0.75mm; TestPoint-0.75mm
U1: FPC2354; FPC253x
U2: RT9080-3.3; SOT23-5

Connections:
3.3V: C4.1, C5.1, J1.2, J2.2, J7.1, JP1.2 (B), JP4.2 (B), R1.2, R5.2, R8.2, U1.A2 (3V3), U1.A7 (3V3), U1.H2 (3V3), U1.H7 (3V3), U2.5 (VOUT)
CFG1: JP2.1 (A), R6.2, U1.D7 (IF_CFG_1)
CFG2: JP3.1 (A), R7.2, U1.C7 (IF_CFG_2)
DM: J4.A7 (D-), J4.B7 (D-), U1.G5 (DM)
DP: J4.A6 (D+), J4.B6 (D+), U1.G6 (DP)
EGND: JP5.1 (A), ST5.1, ST6.1, ST7.1, ST8.1, U1.A1 (EGND), U1.A8 (EGND), U1.H1 (EGND), U1.H8 (EGND)
EN: J5.2, R9.1, U2.3 (EN)
GND: C2.2, C3.2, C4.2, C5.2, D1.1 (K), D2.1 (K), J1.1, J2.1, J4.GND, J4.S (SHIELD), J7.6, JP5.2 (B), R2.1, R4.1, R6.1, R7.1, U1.B1 (GND), U1.B8 (GND), U1.G1 (GND), U1.G8 (GND), U2.2 (GND)
GPIO1: J7.5, R10.2, U1.B7 (GPIO1)
IRQ: J7.2, U1.E7 (IRQ)
unnamed: D1.2 (A), R3.1
unnamed: D2.2 (A), R10.1
unnamed: J4.A5 (CC1), R4.2
unnamed: J4.B5 (CC2), R2.2
unnamed: JP1.1 (A), R3.2
unnamed: JP2.2 (B), R5.1
unnamed: JP3.2 (B), R8.1
unnamed: JP4.1 (A), R12.2
unnamed: JP4.3 (C), R11.2
PICO: J5.6, U1.F2 (PICO)
POCI: J5.5, U1.D2 (POCI)
RX: J7.4, U1.G4 (RX)
SCK: J5.4, U1.E2 (SCK)
SCL: J1.4, J2.4, J3.1, R12.1, U1.B5 (SCL)
SDA: J1.3, J2.3, J6.1, R11.1, U1.B4 (SDA)
TX: J7.3, U1.G3 (TX)
VBUS: C2.1, C3.1, J4.VBUS, R9.2, TP2.1, U2.1 (VIN)
~CS: J5.3, U1.C2 (~CS)
~RST: J5.1, R1.1, U1.B6 (~RST)

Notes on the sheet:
USB Track Impedance: Coplanar Differential Pair @ 90Ω https://jlcpcb.com/pcb-impedance-calculator Board Thickness: 1.6mm Layers: 4 Er: 4.4 (7628 Prepreg) Dielectric Thickness (Layer 1 to 2): 8.28mil/0.21mm (JLC7628) Copper Thickness (1oz outer / 0.5oz inner): 1.38mil/0.035mm Polygon Isolation: 7mil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
I²C Pull-Ups
Cut BZL to isolate bezel connections from ground
USB
Open
CFG1
Driven via software command
Cut jumper to remove pull-ups
I²C
Default interface is I²C
Closed
Interface Selection
UART
Voltage Regulation
Cut jumper to turn off power LED
Interface
7-bit Unshifted I²C Address: 0x24
Power LED
SPI
CFG2
Scan LED
Connectors
Fingerprint Sensor

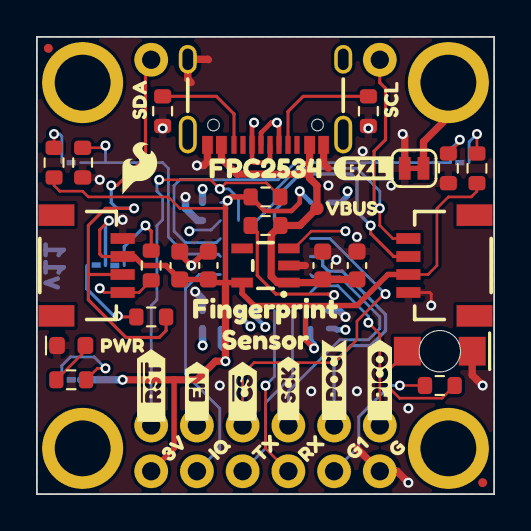
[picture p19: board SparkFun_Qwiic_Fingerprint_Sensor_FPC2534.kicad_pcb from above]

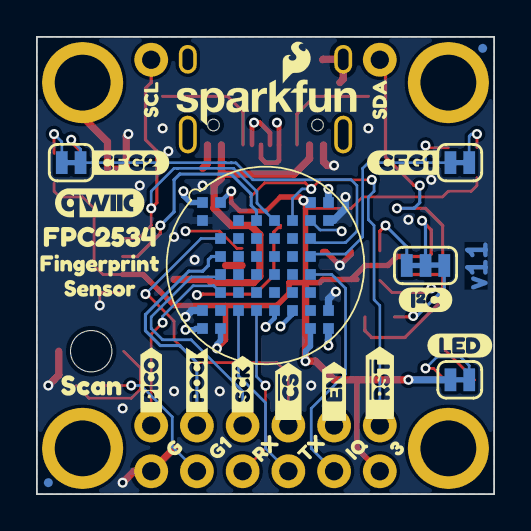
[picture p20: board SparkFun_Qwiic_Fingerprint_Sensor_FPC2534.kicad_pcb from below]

Board: 4 copper layers, 25.4 x 25.4 mm, 84 parts (29 on the bottom side), 29 nets.

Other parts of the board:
kibuzzard-68A62B00: G***; kibuzzard-68A62B00
kibuzzard-68B211A8: G***; kibuzzard-68B211A8
kibuzzard-68B211AF: G***; kibuzzard-68B211AF
kibuzzard-68B211BC: G***; kibuzzard-68B211BC
kibuzzard-68B211C4: G***; kibuzzard-68B211C4
kibuzzard-68B212A1: G***; kibuzzard-68B212A1
kibuzzard-68B2110A: G***; kibuzzard-68B2110A
kibuzzard-68B2118A: G***; kibuzzard-68B2118A
kibuzzard-68B2127B: G***; kibuzzard-68B2127B
kibuzzard-68B21103: G***; kibuzzard-68B21103
kibuzzard-68B21113: G***; kibuzzard-68B21113
kibuzzard-68B21123: G***; kibuzzard-68B21123
kibuzzard-68B21145: G***; kibuzzard-68B21145
kibuzzard-68B21150: G***; kibuzzard-68B21150
kibuzzard-68B21159: G***; kibuzzard-68B21159
kibuzzard-68B21162, kibuzzard-68B21162#2: G***; kibuzzard-68B21162
kibuzzard-68B21169, kibuzzard-68B21169#2: G***; kibuzzard-68B21169
kibuzzard-68B21179: G***; kibuzzard-68B21179
kibuzzard-68B21181: G***; kibuzzard-68B21181
kibuzzard-68B21196: G***; kibuzzard-68B21196
kibuzzard-68B21259: G***; kibuzzard-68B21259
kibuzzard-68B21262: G***; kibuzzard-68B21262
kibuzzard-68B21280: G***; kibuzzard-68B21280
kibuzzard-68B21331: G***; kibuzzard-68B21331
kibuzzard-68BB5A49: G***; kibuzzard-68BB5A49
kibuzzard-68BB5B7A: G***; kibuzzard-68BB5B7A
kibuzzard-68BB5B8B: G***; kibuzzard-68BB5B8B
kibuzzard-68BB5B69: G***; kibuzzard-68BB5B69
kibuzzard-68BB5B72: G***; kibuzzard-68BB5B72
kibuzzard-68BB5B86: G***; kibuzzard-68BB5B86
kibuzzard-68BB5BA4: G***; kibuzzard-68BB5BA4
kibuzzard-68BB5BAA: G***; kibuzzard-68BB5BAA
kibuzzard-68BB5BB0: G***; kibuzzard-68BB5BB0
kibuzzard-68BB5BE0: G***; kibuzzard-68BB5BE0
kibuzzard-68BB5BFB: G***; kibuzzard-68BB5BFB
kibuzzard-68C08F5C: G***; kibuzzard-68C08F5C
kibuzzard-68C08F6E, kibuzzard-68C08F6E#2: G***; kibuzzard-68C08F6E
kibuzzard-68C08FA6: G***; kibuzzard-68C08FA6
kibuzzard-68C0923F: G***; kibuzzard-68C0923F

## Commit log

2025-08-29 Add I2C pull ups and jumper. Adjust silk.
    [SparkFun_Qwiic_Fingerprint_Sensor_FPC2534.kicad_pcb, SparkFun_Qwiic_Fingerprint_Sensor_FPC2534.kicad_sch]
2025-09-09 Post design review.
    [SparkFun_Qwiic_Fingerprint_Sensor_FPC2534.kicad_pcb, SparkFun_Qwiic_Fingerprint_Sensor_FPC2534.kicad_sch]
2025-09-09 Add panel files
    [SparkFun_Qwiic_Fingerprint_Sensor_FPC2534_panelized.GBL, SparkFun_Qwiic_Fingerprint_Sensor_FPC2534_panelized.GBO, SparkFun_Qwiic_Fingerprint_Sensor_FPC2534_pan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]
2025-09-09 Roll PCB version forward
    [SparkFun_Qwiic_Fingerprint_Sensor_FPC2534.kicad_pcb]

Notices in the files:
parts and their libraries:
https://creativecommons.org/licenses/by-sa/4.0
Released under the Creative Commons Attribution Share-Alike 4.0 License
